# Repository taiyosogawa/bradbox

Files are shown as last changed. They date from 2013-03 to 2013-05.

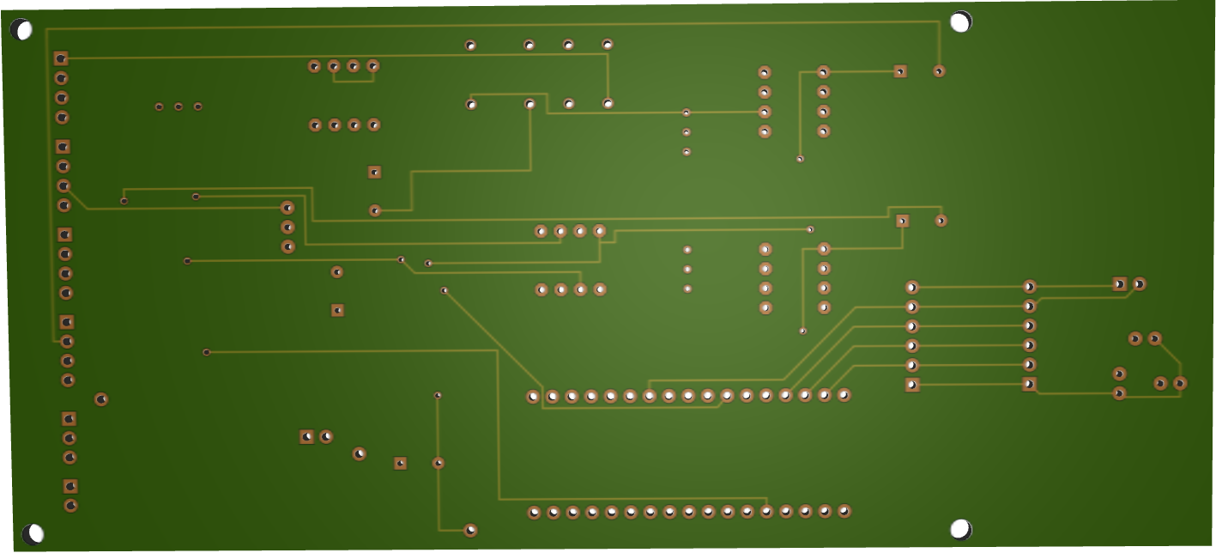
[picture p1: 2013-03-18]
PCB/render_bottom.png

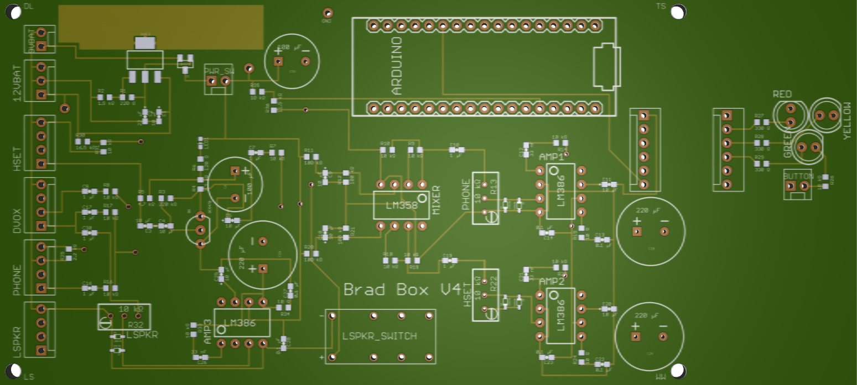
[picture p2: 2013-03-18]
PCB/render_top.png

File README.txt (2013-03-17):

==========
= README =
==========
Author: Taiyo Sogawa
Last Revised: 3/17/2013

=======================
= System Requirements =
=======================
Device: Windows XP 32-bit Operating System

1) Install Java SE 7 JRE
	See:	<http://www.oracle.com/technetwork/java/javase/downloads/index.html>

============================
= Application Installation =
============================

1) Double click on Install_Brad_Box.exe
	This should automatically:
		Put the platform-tools directory in the root directory (Do not delete C:\platform-tools after installation!)
		Put rxtxSerial.dll, sqlite3.def, sqlite3.dll, and sqlite3.exe in C:\WINDOWS\System32
		Put an "Brad Box.exe" on the desktop
	If anything fails, make sure these files are located in the appropriate directories. Manually copying the files might be necessary.

========================
= Arduino Installation =
========================
Device: Arduino Micro

1) Install Driver for Arduino Micro 
	Drivers are located in the setup/arduino-drivers directory 
2) Change device port to COM34
	Control Panel > System Properties > Device Manager
	Find Arduino Micro under Ports
	Right Click > Properties > Port Settings > Advanced
	Change port number to COM34

========================
= Android Installation =
========================
Device: Unlocked Samsung Galaxy Pocket S5300

1) Install phone drivers on computer (Directions vary by device.)
	Drivers for Galaxy Pocket are in the setup/android-drivers directory
2) Factory reset the phone if desired (Directions vary by device.)
	On the Galaxy Pocket, Dial *2767*3855#
3) Root the android phone (Directions vary by device.)
4) Enable USB Debug Mode (Directions vary by device.)
	On the Galaxy Pocket, Settings > Applications > Development > USB debugging 
5) Install Android application
	Connect phone to computer by USB
	You can check the connection by opening CMD, navigating to C:\platform-tools and typing command "adb devices"
	Double click install_new_android_application.exe in C:\platform-tools when phone connected
	You will see the Brad Box logo on the phone screen on a successful install

============================
= Additional Documentation =
============================

https://code.google.com/p/aster/source/browse/src/com/android/chimpchat/core/IChimpDevice.java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

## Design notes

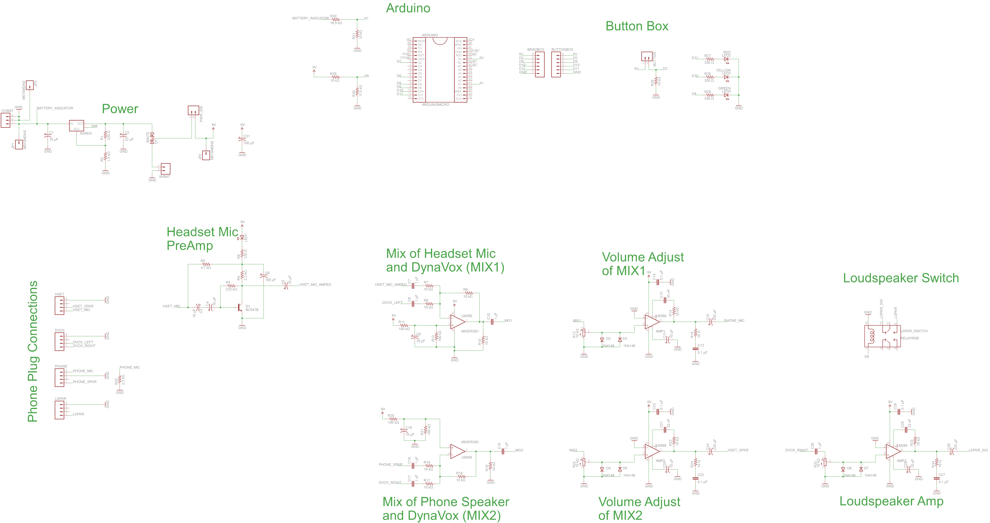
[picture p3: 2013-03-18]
PCB/schematic.png

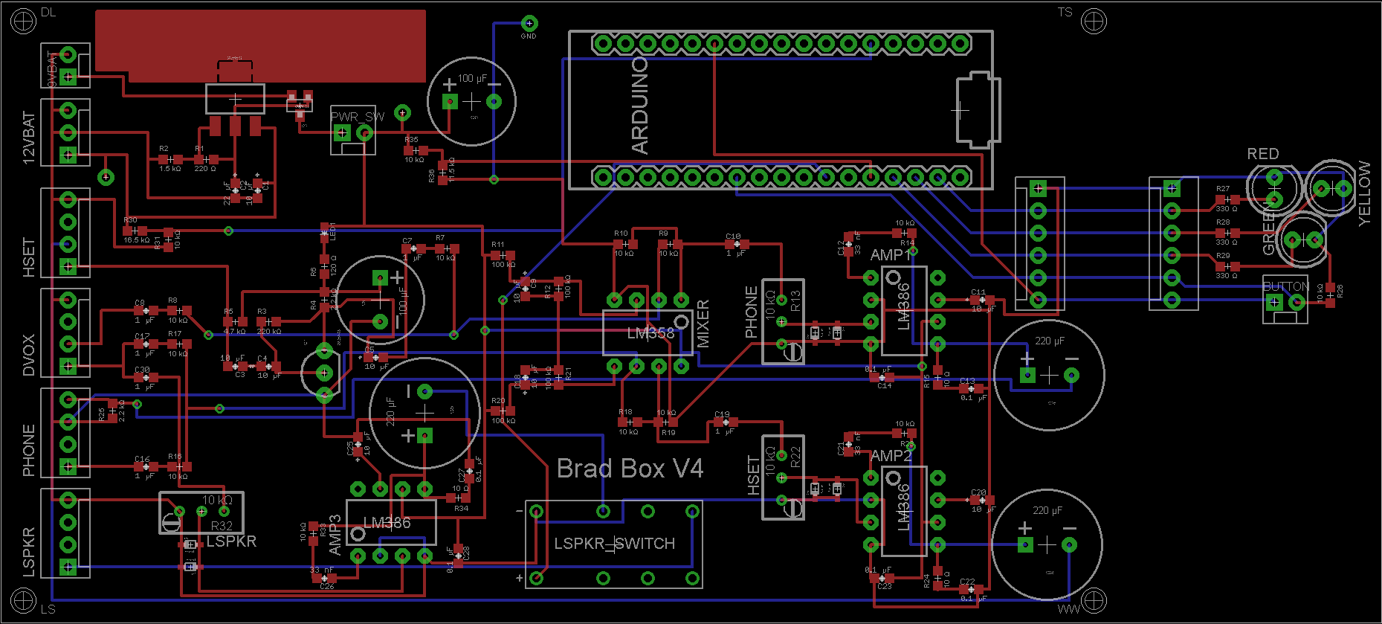
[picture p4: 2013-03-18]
PCB/pcb.png

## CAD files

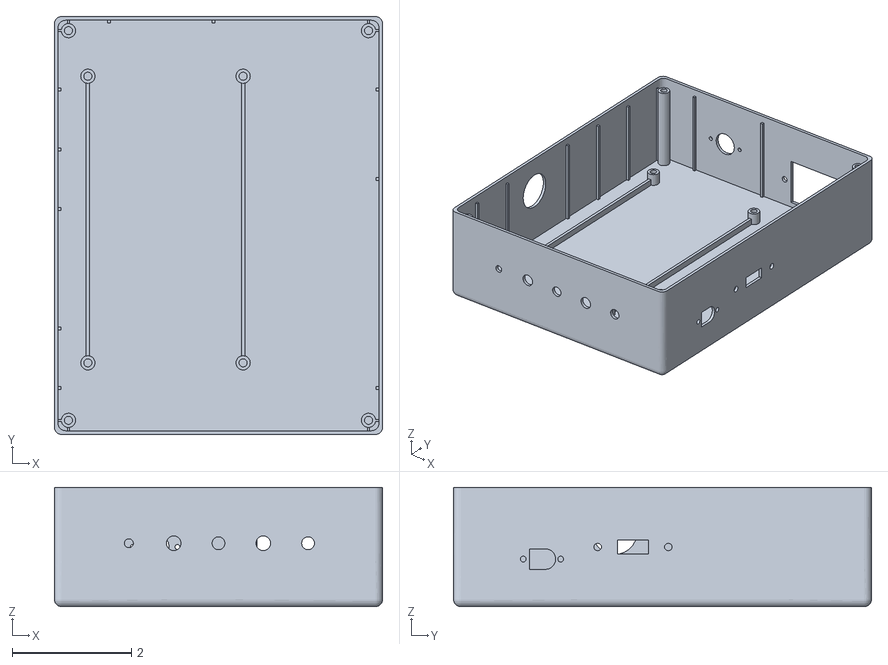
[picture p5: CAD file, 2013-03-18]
Brad Box Housing/BradBox_Bottom.stl
5.50 x 7.00 x 2.00

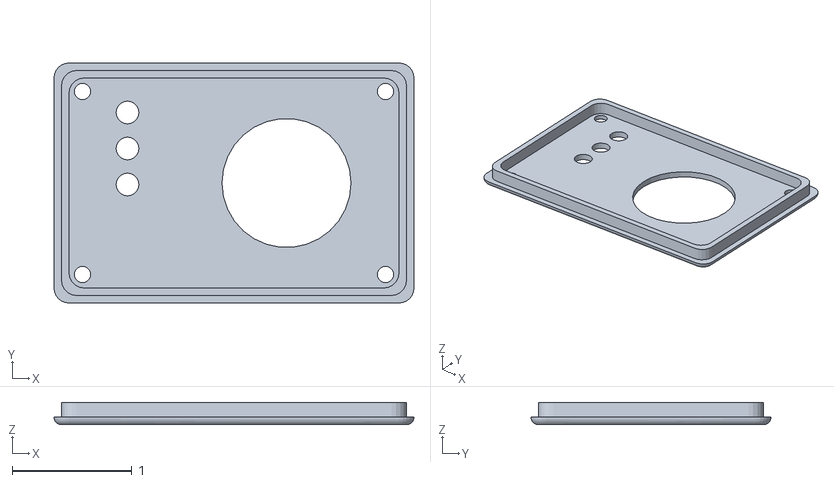
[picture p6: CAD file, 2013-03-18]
Push Button Housing/Push Button Top.stl
3.00 x 2.00 x 0.188

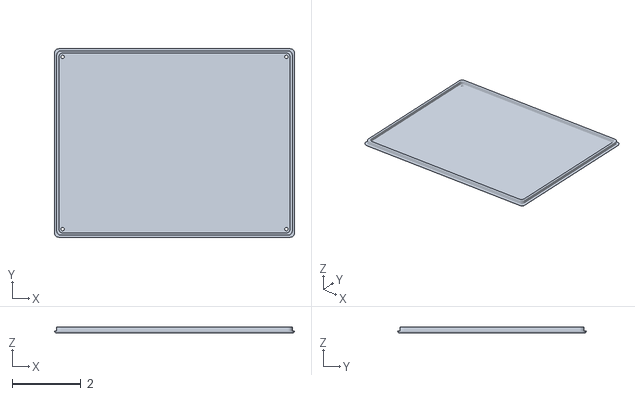
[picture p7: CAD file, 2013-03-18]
Brad Box Housing/BradBox_Top.stl
7.00 x 5.50 x 0.188

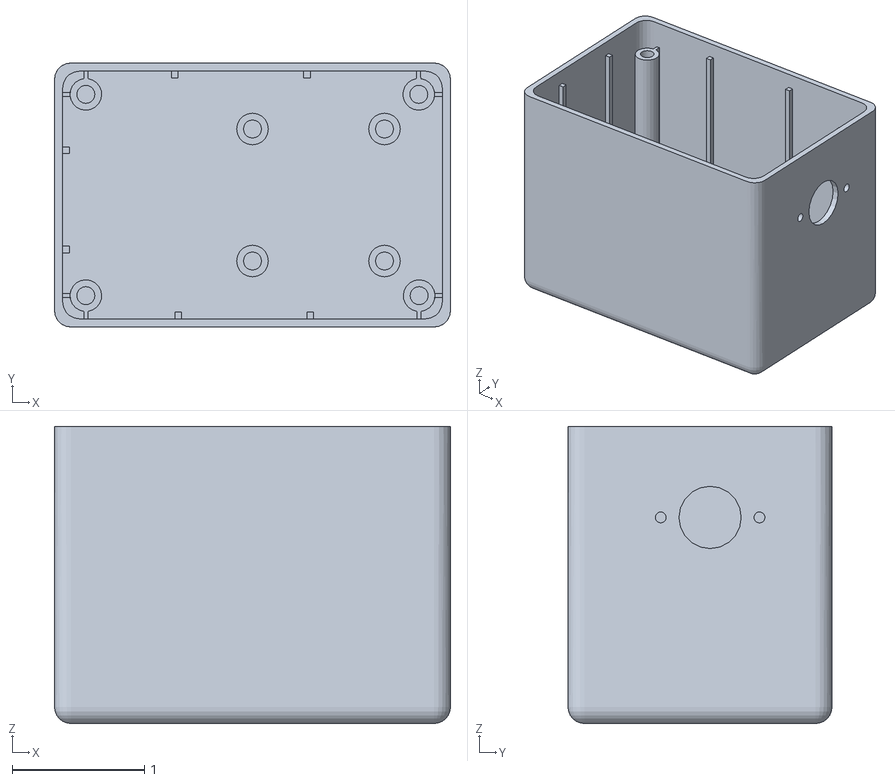
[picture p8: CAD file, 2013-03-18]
Push Button Housing/Push Button Bottom.stl
3.00 x 2.00 x 2.25

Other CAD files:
Brad Box Housing/25_Jack.prt
Brad Box Housing/35TRRS_Jack.prt
Brad Box Housing/35TRS_Jack.prt
Brad Box Housing/35TS_Jack.prt
Brad Box Housing/6pinOutlet.prt
Brad Box Housing/ArduinoMicro.prt
Brad Box Housing/BB_PCB.prt
Brad Box Housing/Battery Box.prt
Brad Box Housing/Brad Box Top.prt
Brad Box Housing/BradBox.prt
Brad Box Housing/BradBoxBottom.prt
Brad Box Housing/BradBoxTop.prt
Brad Box Housing/BradBox_Dimensions.prt
Brad Box Housing/CapacitorLarge.prt
Brad Box Housing/ON_Button.prt
Brad Box Housing/Plug.prt
Brad Box Housing/Power.prt
Brad Box Housing/USB_mount.prt
Push Button Housing/CallButton.prt
Push Button Housing/LED.prt
Push Button Housing/PBB.prt
Push Button Housing/PBB_Bottom.prt
Push Button Housing/PBB_PCB.prt
Push Button Housing/PBB_Top.prt

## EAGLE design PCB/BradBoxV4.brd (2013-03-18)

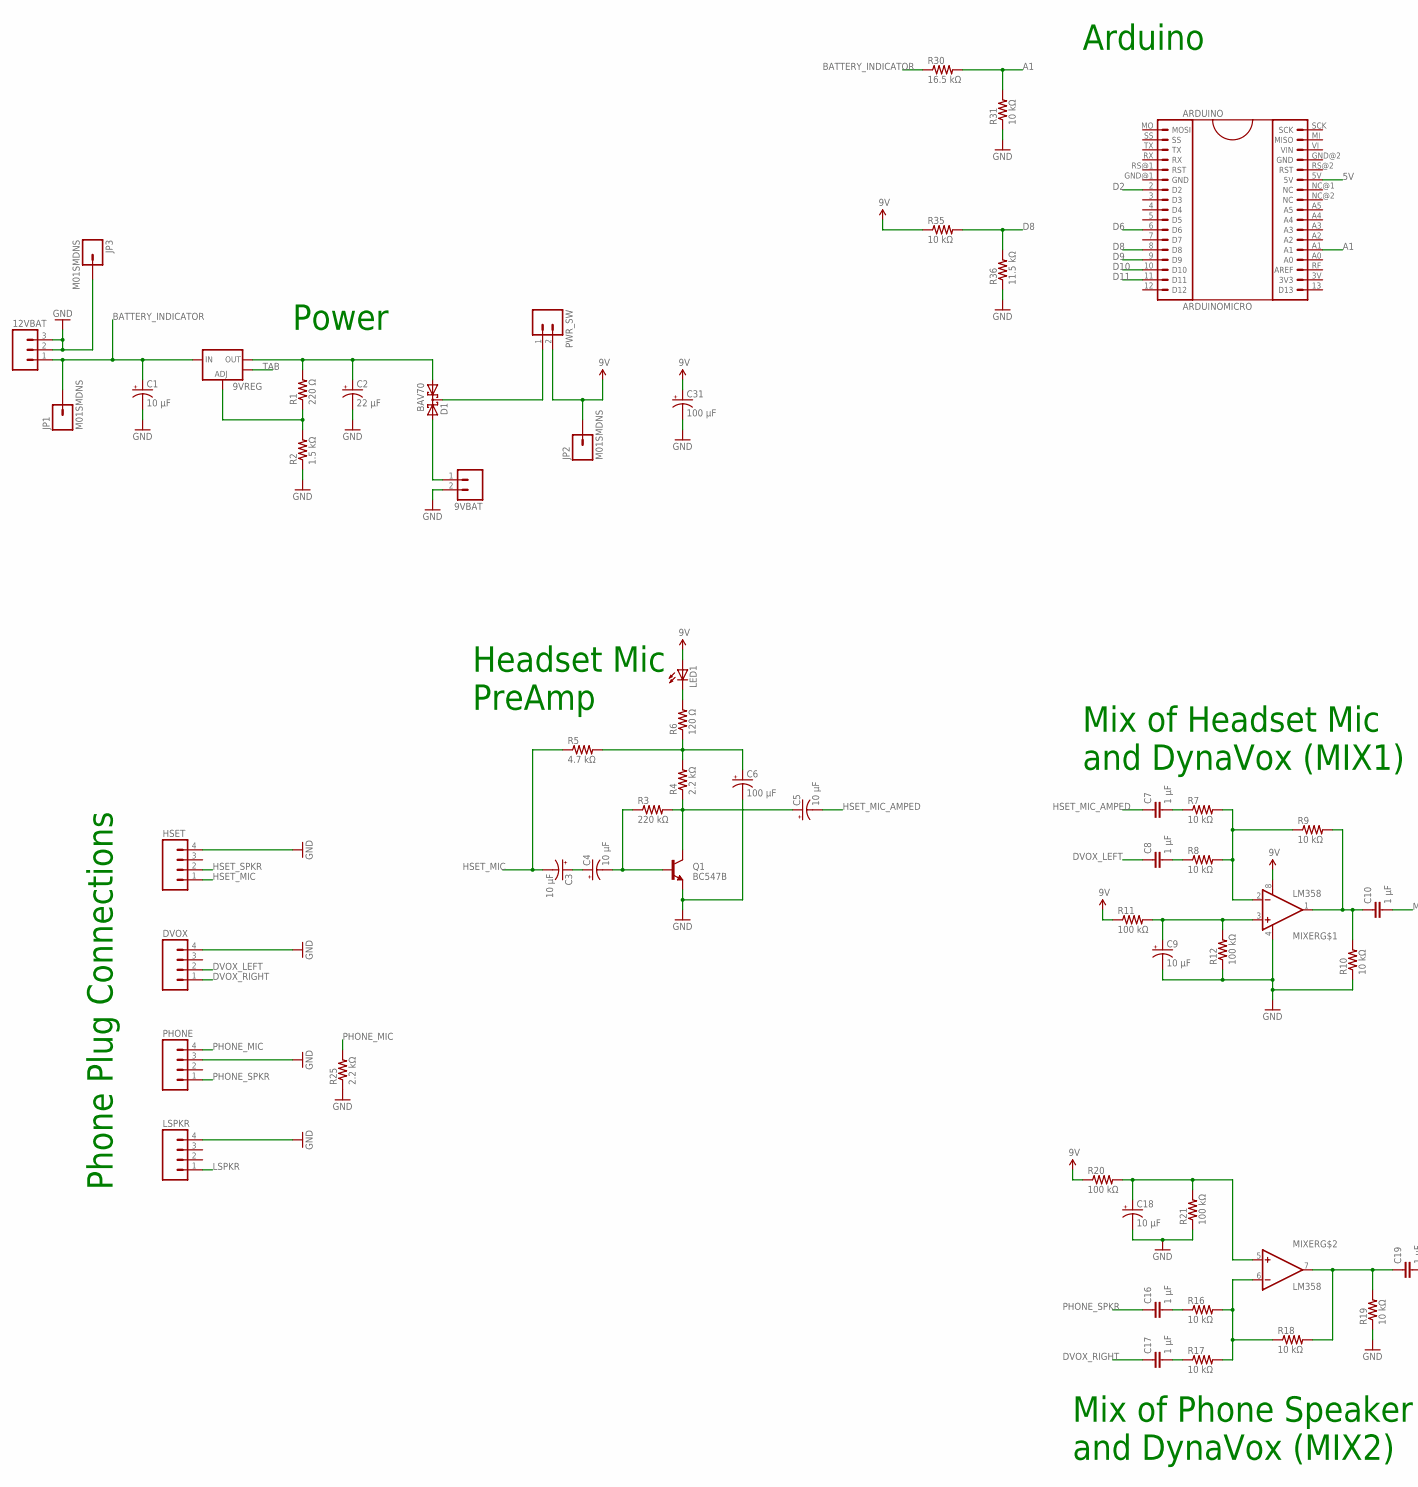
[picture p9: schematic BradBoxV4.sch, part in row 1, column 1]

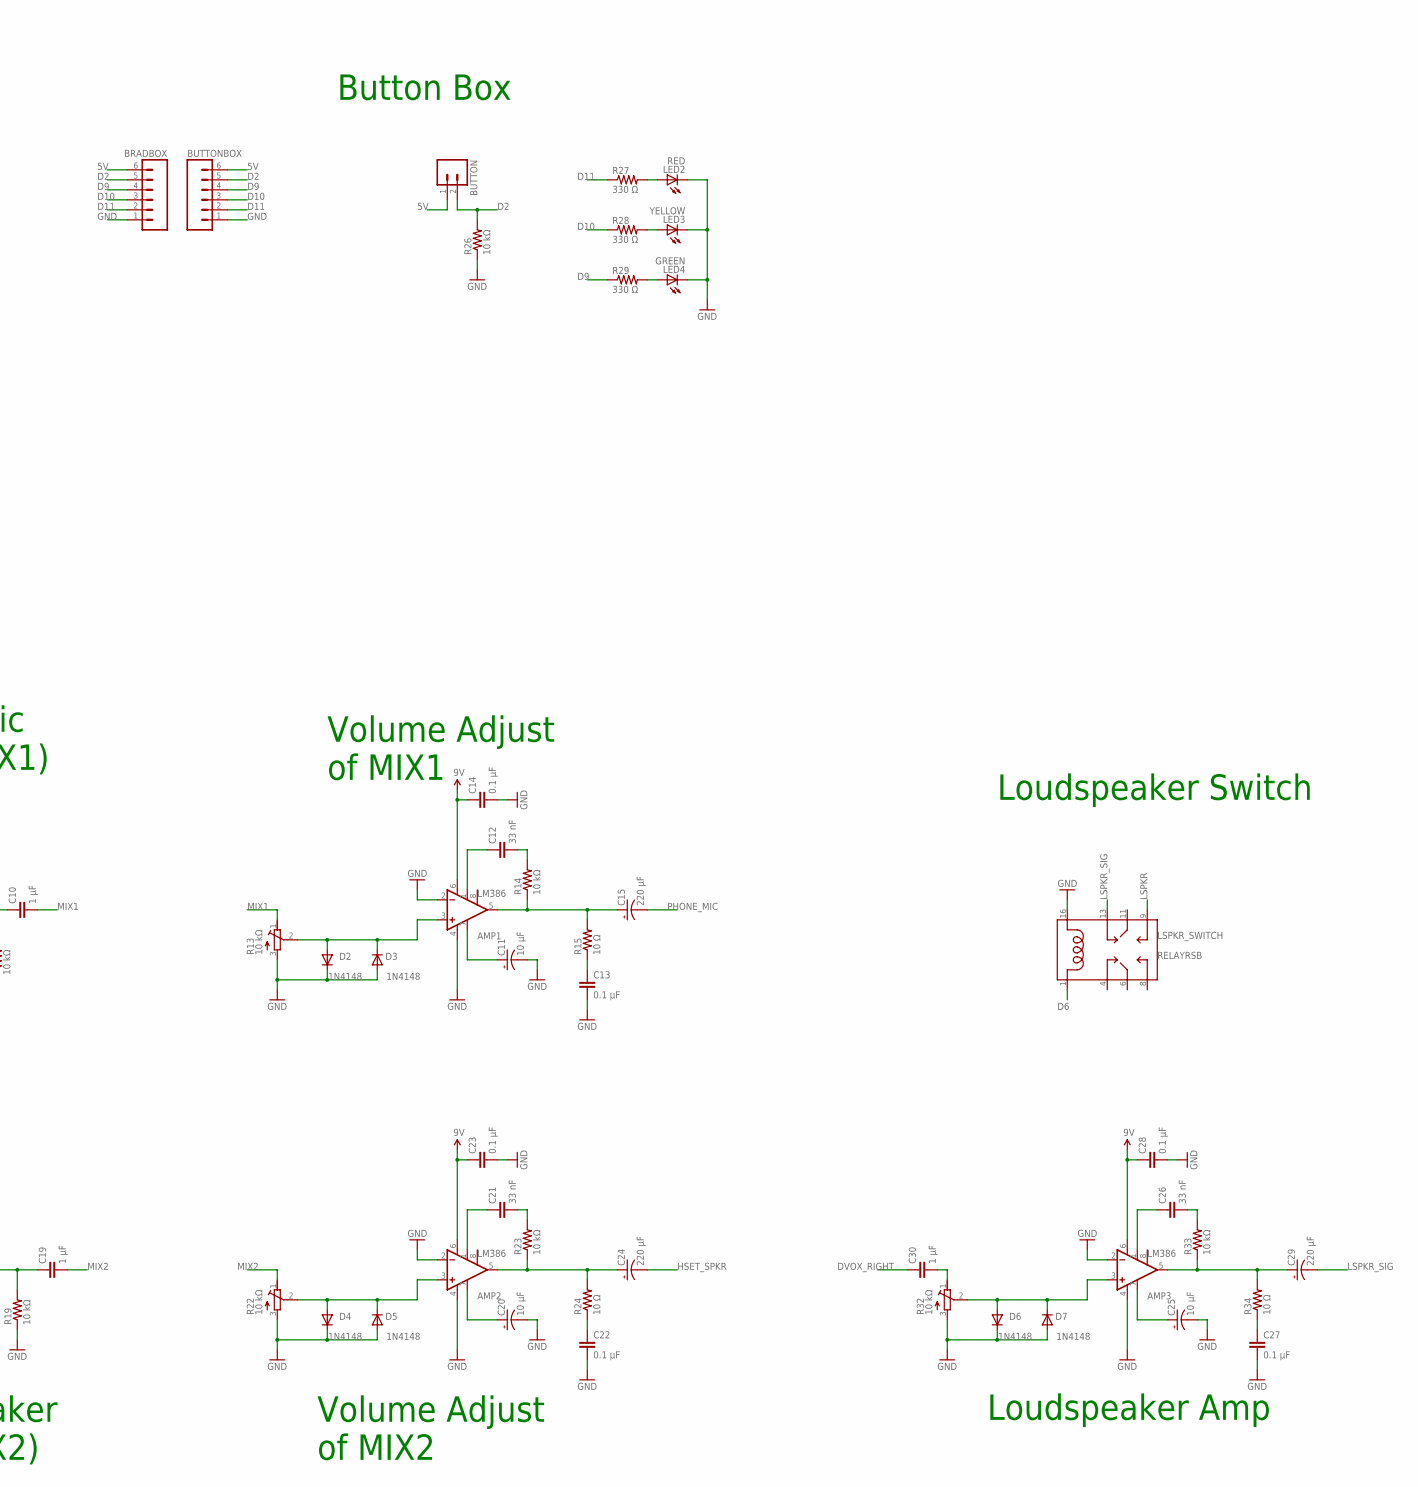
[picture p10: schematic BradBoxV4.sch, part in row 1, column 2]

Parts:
9VBAT: M02POLAR; MOLEX-1X2
9VREG: V_REG_LM1117SOT223; SOT223
12VBAT: M03POLAR; MOLEX-1X3
AMP1, AMP2, AMP3: LM386; DIP08
ARDUINO: ARDUINOMICRO; ARDUINO_MICRO
BRADBOX: M06POLAR; MOLEX-1X6
BUTTON: M02POLAR; MOLEX-1X2
BUTTONBOX: M06POLAR; MOLEX-1X6
C1, C3, C4, C5, C9, C11, C18, C20, C25: 10 µF; 0603-CAP-POL
C2: 22 µF; 0603-CAP-POL
C6, C31: 100 µF; CPOL-RADIAL-100UF-100V
C7, C8, C10, C16, C17, C19, C30: 1 µF; 0603-CAP
C12, C21, C26: 33 nF; 0603-CAP
C13, C14, C22, C23, C27, C28: 0.1 µF; 0603-CAP
C15, C24, C29: 220 µF; CPOL-RADIAL-220UF-100V
D1: BAV70; SOT23
D2, D3, D4, D5, D6, D7: 1N4148; SOD523F
DVOX: M04POLAR; MOLEX-1X4
HSET: M04POLAR; MOLEX-1X4
JP1, JP2, JP3: M01SMDNS; 1X01NS
LED1: LED0603; LED-0603
LED2: RED; LED5MM
LED3: YELLOW; LED5MM
LED4: GREEN; LED5MM
LSPKR: M04POLAR; MOLEX-1X4
LSPKR_SWITCH: RELAYRSB; RELAY-RSB
MIXER: LM358; DIP08
PHONE: M04POLAR; MOLEX-1X4
PWR_SW: M02POLAR; MOLEX-1X2
Q1: BC547B; TO-92-AMMO
R1: 220 Ω; R0603
R2: 1.5 kΩ; R0603
R3: 220 kΩ; R0603
R4, R25: 2.2 kΩ; R0603
R5: 4.7 kΩ; R0603
R6: 120 Ω; R0603
R7, R8, R9, R10, R14, R16, R17, R18, R19, R23, R26, R31, R33, R35: 10 kΩ; R0603
R11, R12, R20, R21: 100 kΩ; R0603
R13, R22, R32: 10 kΩ; RTRIMT93YA
R15, R24, R34: 10 Ω; R0603
R27, R28, R29: 330 Ω; R0603
R30: 16.5 kΩ; R0603
R36: 11.5 kΩ; R0603

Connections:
5V: ARDUINO.5V, BRADBOX.6, BUTTON.1, BUTTONBOX.6
9V: AMP1.6 (V+), AMP2.6 (V+), AMP3.6 (V+), C14.1, C23.1, C28.1, C31.1 (+), JP2.1, LED1.A, MIXER.8 (V+), PWR_SW.2, R11.1, R20.1, R35.1
A1: ARDUINO.A1, R30.2, R31.2
BATTERY_INDICATOR: 9VREG.3 (IN), 12VBAT.1, C1.1 (+), JP1.1, R30.1
D2: ARDUINO.2 (D2), BRADBOX.5, BUTTON.2, BUTTONBOX.5, R26.2
D6: ARDUINO.6 (D6), LSPKR_SWITCH.1
D8: ARDUINO.8 (D8), R35.2, R36.2
D9: ARDUINO.9 (D9), BRADBOX.4, BUTTONBOX.4, R29.1
D10: ARDUINO.10 (D10), BRADBOX.3, BUTTONBOX.3, R28.1
D11: ARDUINO.11 (D11), BRADBOX.2, BUTTONBOX.2, R27.1
DVOX_LEFT: C8.1, DVOX.2
DVOX_RIGHT: C17.1, C30.1, DVOX.1
GND: 9VBAT.2, 12VBAT.2, 12VBAT.3, AMP1.2 (-IN), AMP1.4 (V-), AMP2.2 (-IN), AMP2.4 (V-), AMP3.2 (-IN), AMP3.4 (V-), BRADBOX.1, BUTTONBOX.1, C1.2 (-), C2.2 (-), C6.2 (-), C9.2 (-), C11.2 (-), C13.2, C14.2, C18.2 (-), C20.2 (-), C22.2, C23.2, C25.2 (-), C27.2, C28.2, C31.2 (-), D2.C, D3.A, D4.C, D5.A, D6.C, D7.A, DVOX.4, HSET.4, JP3.1, LED2.K (C), LED3.K (C), LED4.K (C), LSPKR.4, LSPKR_SWITCH.16, MIXER.4 (V-), PHONE.3, Q1.1 (E), R2.1, R10.1, R12.1, R13.3 (E), R19.1, R21.1, R22.3 (E), R25.1, R26.1, R31.1, R32.3 (E), R36.1
HSET_MIC: C3.2 (-), HSET.1, R5.1
HSET_MIC_AMPED: C5.2 (-), C7.1
HSET_SPKR: C24.2 (-), HSET.2
LSPKR: LSPKR.1, LSPKR_SWITCH.9
LSPKR_SIG: C29.2 (-), LSPKR_SWITCH.13
MIX1: C10.2, R13.1 (A)
MIX2: C19.2, R22.1 (A)
unnamed: 9VREG.2 (OUT), C2.1 (+), D1.1 (A1), R1.2
unnamed: 9VREG.1 (ADJ), R1.1, R2.2
unnamed: AMP3.3 (+IN), D6.A, D7.C, R32.2 (S)
unnamed: D1.3 (C), PWR_SW.1
unnamed: 9VBAT.1, D1.2 (A2)
unnamed: C3.1 (+), C4.1 (+)
unnamed: C4.2 (-), Q1.2 (B), R3.1
unnamed: C5.1 (+), Q1.3 (C), R3.2, R4.1
unnamed: LED1.C, R6.2
unnamed: C6.1 (+), R4.2, R5.2, R6.1
unnamed: C8.2, R8.1
unnamed: C7.2, R7.1
unnamed: MIXER.2 (-IN), R7.2, R8.2, R9.1
unnamed: C10.1, MIXER.1 (OUT), R9.2, R10.2
unnamed: C9.1 (+), MIXER.3 (+IN), R11.2, R12.2
unnamed: AMP1.1 (GAIN), C12.1
unnamed: C12.2, R14.2
unnamed: AMP1.3 (+IN), D2.A, D3.C, R13.2 (S)
unnamed: AMP1.5 (OUT), C15.1 (+), R14.1, R15.2
unnamed: AMP1.7 (BP), C11.1 (+)
unnamed: C13.1, R15.1
unnamed: C17.2, R17.1
unnamed: C16.2, R16.1
unnamed: C18.1 (+), MIXER.5 (+IN), R20.2, R21.2
unnamed: MIXER.6 (-IN), R16.2, R17.2, R18.1
unnamed: C19.1, MIXER.7 (OUT), R18.2, R19.2
unnamed: AMP2.3 (+IN), D4.A, D5.C, R22.2 (S)
unnamed: AMP2.7 (BP), C20.1 (+)
unnamed: AMP2.1 (GAIN), C21.1
unnamed: C21.2, R23.2
unnamed: AMP2.5 (OUT), C24.1 (+), R23.1, R24.2
unnamed: C22.1, R24.1
unnamed: LED2.A, R27.2
unnamed: LED3.A, R28.2
unnamed: LED4.A, R29.2
unnamed: AMP3.7 (BP), C25.1 (+)
unnamed: AMP3.1 (GAIN), C26.1
unnamed: C26.2, R33.2
unnamed: AMP3.5 (OUT), C29.1 (+), R33.1, R34.2
unnamed: C27.1, R34.1
unnamed: C30.2, R32.1 (A)
PHONE_MIC: C15.2 (-), PHONE.4, R25.2
PHONE_SPKR: C16.1, PHONE.1
TAB: 9VREG.4 (OUT)

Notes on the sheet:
Phone Plug Connections
Power
Headset Mic PreAmp
Mix of Headset Mic and DynaVox (MIX1)
Volume Adjust of MIX1
Mix of Phone Speaker and DynaVox (MIX2)
Volume Adjust of MIX2
Arduino
Button Box
Loudspeaker Amp
Loudspeaker Switch

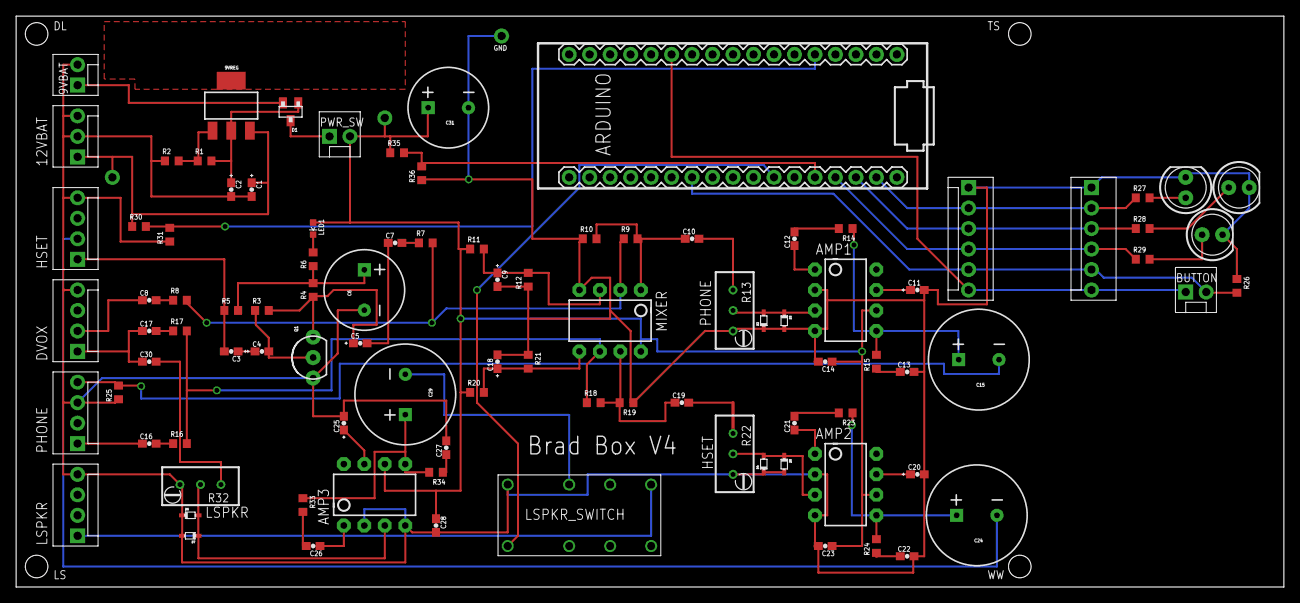
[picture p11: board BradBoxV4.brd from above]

Board: 2 copper layers, 157.2 x 70.8 mm, 99 parts (0 on the bottom side), 63 nets.

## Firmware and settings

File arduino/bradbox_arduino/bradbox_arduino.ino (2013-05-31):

#define buttonPin 2                 // button on pin 2
#define loudspeakerPin 6            // high for loudspeaker on, low for loudspeaker off
#define ledPin 13
#define debounceDelay 50            // 50 millisecond delay on the button debounce
#define longHoldDelay 3000           // hold the button for 3 seconds for a long hold to be activated

int battery = A1;    // select the input pin for the battery
int redPin = 11;     // select the pin for the red LED
int yellowPin = 10;  // select the pin for the yellow LED
int greenPin = 9;    // select the pin for the green LED
int isPowerOn = 8;   // select the pin for checking power

int batteryValue = 0;  // variable to store the value coming from the battery
int powerState = 0;    // variable to store the value coming from the power

int buttonState = 0;  // 0 = rest, 1 = debounce_hold, 2 = short_hold, 3 = short_debounce_time, 4 = long_hold
long startTime;       // The time when button transitions from state 0 to state 1
long debounceStartTime; // the time when button transitions from state 2 to state 3

char loudspeakerChar; // 'h' for high (on), 'l' for low (off)

void setup() {
   Serial.begin(9600);              // setup serial with 9600 baud rate
   
   pinMode(ledPin, OUTPUT);
   pinMode(redPin, OUTPUT); 
   pinMode(yellowPin, OUTPUT);
   pinMode(greenPin, OUTPUT);
   pinMode(isPowerOn, INPUT);
   
   pinMode(loudspeakerPin, OUTPUT);
   digitalWrite(loudspeakerPin, LOW);
   
   pinMode(buttonPin, INPUT);
   digitalWrite(buttonPin, HIGH);   
}

void loop() {
  
  //---------------------------------------------
  // Handle the battery reading
  //---------------------------------------------
   // read the value from the battery:
  batteryValue = analogRead(battery);
  
  // see if the power to the whole circuit is on
  powerState = digitalRead(isPowerOn);
  
  // turn on the right color LED
  // turn on none if the circuit does not have power
  if (powerState == HIGH) {
    if (batteryValue > 928) {
      analogWrite(greenPin, 10);
      analogWrite(yellowPin, 0);
      analogWrite(redPin, 0);       
    } else if (batteryValue > 898) {
      analogWrite(greenPin, 0);
      analogWrite(yellowPin, 10);
      analogWrite(redPin, 0);
    } else {
      analogWrite(greenPin, 0);
      analogWrite(yellowPin, 0);
      analogWrite(redPin, 20);
    }
  } else {
      analogWrite(greenPin, 0);
      analogWrite(yellowPin, 0);
      analogWrite(redPin, 0);
  }
  
  
  
   //---------------------------------------------
   // check for loudspeaker
   //---------------------------------------------
   loudspeakerChar = Serial.read();
   if(loudspeakerChar == 'h') {
     digitalWrite(loudspeakerPin, HIGH);  
     digitalWrite(ledPin, HIGH);  
   } else if(loudspeakerChar == 'l') {
     digitalWrite(loudspeakerPin, LOW);
     digitalWrite(ledPin, LOW);
   }


  //---------------------------------------------
  // Read the button
  //---------------------------------------------
  
  // IMPORTANT: LOW means button is DEPRESSED!!!!
  int buttonValue = digitalRead(buttonPin);
  if (buttonState == 0) {
    // The button is in a rest state
    if (buttonValue == LOW) {
      startTime = millis();
      buttonState = 1;
    }
    
  } else if (buttonState == 1) {
    // The button is in a debounce state
    if (buttonValue == HIGH) {
      buttonState = 0;
    } else if (millis() - startTime > debounceDelay) {
      buttonState = 2;
    }    
    
  } else if (buttonState == 2) {
    // The button has been active for a short amount of time
    if (buttonValue == HIGH) {
      buttonState = 3;
    } else if (millis() - startTime > longHoldDelay) {
      buttonState = 4;
      Serial.println("long");
    }
  } else if (buttonState == 3) {
    if (millis() - startTime > debounceDelay) {
      Serial.println("short");
      buttonState = 0;
    } else if (buttonValue == LOW) {
      buttonState = 2;
    }
    
  } else if (buttonState == 4) {
    // The button has been active for a long amount of time
    if (buttonValue == HIGH) {
      buttonState = 1;
    }
  }
  
}

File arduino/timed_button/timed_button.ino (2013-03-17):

/*
  Timed Button
  
  Informs the user how many seconds a button attached to pin 2 was depressed
  
  The circuit:
  * LED attached from pin 13 to ground (i.e. the LED on board the Arduino Uno)
  * pushbutton attached to pin 2 from +5V
  * 10K resistor attached to pin 2 from ground

*/

#define holdTime 3000
#define minPressTime 20

#define ledPin  13                  // LED connected to digital pin 13
#define buttonPin 2                 // button on pin 2
#define loudspeakerPin 3            // high for loudspeaker on, low for loudspeaker off
int value = LOW;                    // previous value of the LED
int buttonState;                    // variable to store button state
int lastButtonState;                // variable to store last button state
long startTime;                     // start time for stop watch
long elapsedTime;                   // elapsed time for stop watch
int fractional;                     // variable used to store fractional part of time
String output;
char loudspeakerChar;              // 'h' for high (on), 'l' for low (off)

void setup() {
   Serial.begin(9600);              // setup serial with 9600 baud rate
  
   pinMode(ledPin, OUTPUT);         // sets the digital pin as output
   pinMode(buttonPin, INPUT);       // sets the digital pin as input
   pinMode(loudspeakerPin, OUTPUT);
   digitalWrite(loudspeakerPin, LOW);
}

void loop() {
   // check for loudspeaker
   loudspeakerChar = Serial.read();
   if(loudspeakerChar == 'h') {
     digitalWrite(loudspeakerPin, HIGH);
     // This next line should be deleted
     digitalWrite(ledPin, HIGH);
     
   } else if(loudspeakerChar == 'l') {
     digitalWrite(loudspeakerPin, LOW);
     digitalWrite(ledPin, LOW);
   }
   // check for button press
   buttonState = digitalRead(buttonPin);                   // read the button state and store
   
   // check for a low to high transistion (button press)
   if (buttonState == HIGH && lastButtonState == LOW) {    
        startTime = millis();                                // store the start time
        digitalWrite(ledPin, HIGH);                          // turn the LED on
        lastButtonState = HIGH;
        
   } else if (buttonState == HIGH && lastButtonState == HIGH) {   
        elapsedTime = millis() - startTime;              // store elapsed time
        if(elapsedTime == holdTime) {
          Serial.println("long");
          delay(2);
        }
        
   } else if (buttonState == LOW && lastButtonState == HIGH) {
       elapsedTime = millis() - startTime;
       digitalWrite(ledPin, LOW);                         // turn the LED off
       lastButtonState = buttonState;                     // store buttonState in lastButtonState, to compare next time
       if((elapsedTime < holdTime) && (elapsedTime > minPressTime)){
          Serial.println("short");                             // print status
       }
   }
}

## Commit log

2013-01-28 Button push from Arduino will push the call button on the phone
2013-02-04 Long button presses will restart the phone.
2013-02-04 Changed navigation button icons
2013-02-04 Added all images for navigation buttons
2013-02-06 Added texting button
2013-02-21 Changed Keypad Button Sizes
2013-02-23 keypad shows up on phone when switching to keypad panel
2013-02-24 Device restarts with long button press
2013-02-25 can search for contacts when pushing search button
2013-03-03 Loudspeaker controlled from options menu (pin 3 high = loudspeaker on)
2013-03-04 call button on ContactModule will dial and call correct number
2013-03-18 PCB schematics included.
    [BradBoxV4.brd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]
2013-03-18 added files for brad box and push button box
    [25_Jack.prt, 35TRRS_Jack.prt, 35TRS_Jack.prt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]
2013-04-24 updated Arduino code with debounce and no restart option
2013-05-31 Updated arduino code to send 'short' and 'long' messages
    [bradbox_arduino.ino]
2013-05-31 long button push will start and restart BradTrack
